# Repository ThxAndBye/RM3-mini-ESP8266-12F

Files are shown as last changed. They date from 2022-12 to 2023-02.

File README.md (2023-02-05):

# RM3-mini-ESP8266-12F
Replace the original uC PCB from the BroadLink RM3 mini with a ESP8266-12F

# BOM
|Part |Name |Amount  |
|---|---|---|
|R1-R2 |0603 5.1kΩ |2x |
|R3-R6 |0603 10kΩ |4x |
|R7 |0603 |1x |
|C1-C2 |0603 100nF |2x |
|C3-C4 |D5mm P2.5mm radial 47µF|2x |
|C5 |0603 10µF |1x |
|D4 |0603 LED |1x |
|J1 |TYPE-C-31-M-12 |1x |
|J3-J4 |2.54mm pin header |9x |
|U1 |ESP8266-12F |1x |
|U2 |AMS1117 3.3V |1x |
|RST & FLASH|6mm Push button |2x |

# PCB
## Front
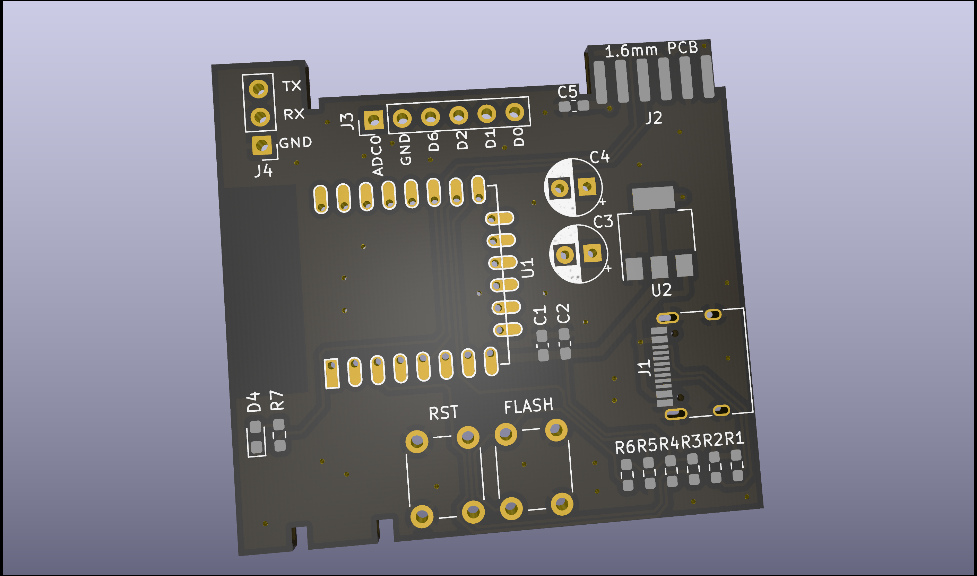
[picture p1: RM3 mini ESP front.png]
PCB front view


## Back
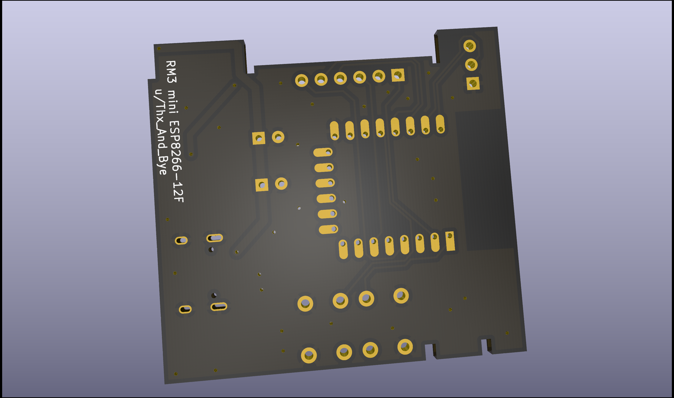
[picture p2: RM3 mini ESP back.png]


## Example ESPHome configuration
This example receives all IR codes and prins them to the log.
It also has the commands configured for the AUDIOPHONICS PRE-03.

```
esphome:
  name: "em3-mini"
  platform: esp8266
  board: esp01_1m

# Enable logging
logger:

# Enable Home Assistant API
api:

ota:

wifi:
  ssid: !secret wifi_ssid
  password: !secret wifi_password

  # Enable fallback hotspot (captive portal) in case wifi connection fails
  ap:
    ssid: "Esphome-Web-09F729"
    password: "QghgvaHWUIw2"

captive_portal:

light:
  - platform: status_led
    id: status
    name: "Status LED"
    pin: GPIO2
    
remote_receiver:
  pin:
    number: GPIO14
    inverted: true
  dump: all

remote_transmitter:
  pin: GPIO13
  carrier_duty_percent: 50%

button:
  - platform: template
    name: "Volume Up"
    on_press:
      - remote_transmitter.transmit_nec:
          address: 0xFF00
          command: 0xEF10
  - platform: template
    name: "Volume Down"
    on_press:
      - remote_transmitter.transmit_nec:
          address: 0xFF00
          command: 0xEB14
  - platform: template
    name: "Mute"
    on_press:
      - remote_transmitter.transmit_nec:
          address: 0xFF00
          command: 0xED12
  - platform: template
    name: "Switch input left"
    on_press:
      - remote_transmitter.transmit_nec:
          address: 0xFF00
          command: 0xEE11
  - platform: template
    name: "Switch input right"
    on_press:
      - remote_transmitter.transmit_nec:
          address: 0xFF00
          command: 0xEC13  
```

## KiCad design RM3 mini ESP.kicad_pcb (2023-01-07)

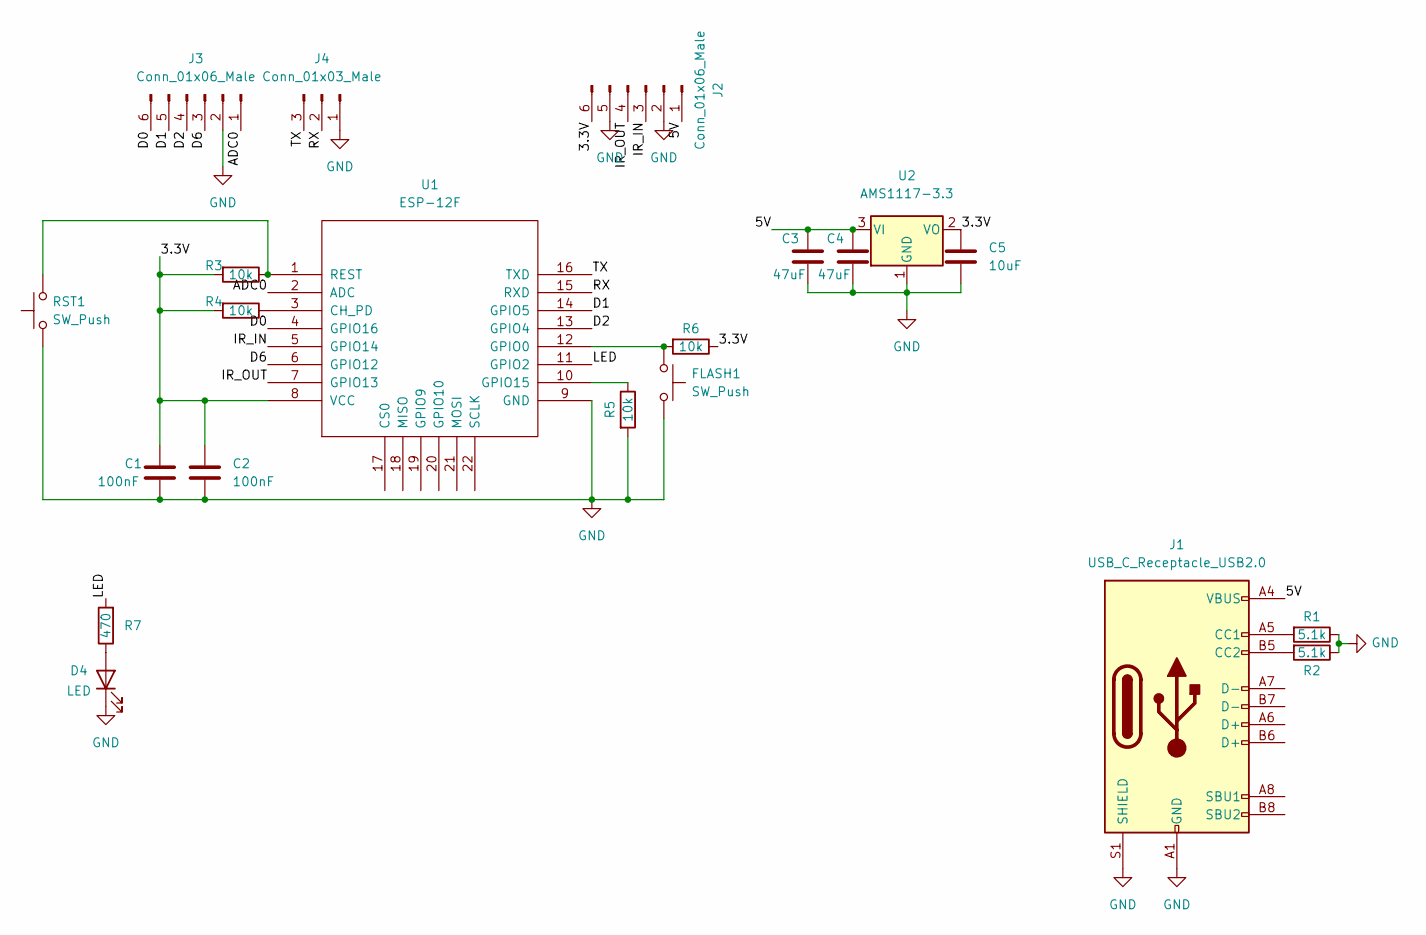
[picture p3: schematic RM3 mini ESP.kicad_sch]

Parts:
C1, C2: 100nF; C_0603_1608Metric_Pad1.08x0.95mm_HandSolder
C3, C4: 47uF; CP_Radial_D5.0mm_P2.50mm
C5: 10uF; C_0603_1608Metric_Pad1.08x0.95mm_HandSolder
D4: LED; LED_0603_1608Metric_Pad1.05x0.95mm_HandSolder
FLASH1: SW_Push; SW_PUSH_6mm_H8mm
J1: USB_C_Receptacle_USB2.0; USB_C_Receptacle_HRO_TYPE-C-31-M-12
J2: Conn_01x06_Male; SolderWirePad_1x01_SMD_1x2mm
J3: Conn_01x06_Male; PinHeader_1x06_P2.54mm_Vertical
J4: Conn_01x03_Male; PinHeader_1x03_P2.54mm_Vertical
R1, R2: 5.1k; R_0603_1608Metric_Pad0.98x0.95mm_HandSolder
R3, R4, R5, R6: 10k; R_0603_1608Metric_Pad0.98x0.95mm_HandSolder
R7: 470; R_0603_1608Metric_Pad0.98x0.95mm_HandSolder
RST1: SW_Push; SW_PUSH_6mm_H8mm
U1: ESP-12F; ESP-12E
U2: AMS1117-3.3; SOT-223-3_TabPin2

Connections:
/3.3V: C1.1, C2.1, C5.1, J2.6, R3.2, R4.2, R6.1, U1.8 (VCC), U2.2 (VO)
/5V: C3.1, C4.1, J1.A4 (VBUS), J1.A9 (VBUS), J1.B4 (VBUS), J1.B9 (VBUS), J2.1, U2.3 (VI)
/ADC0: J3.1, U1.2 (ADC)
/D0: J3.6, U1.4 (GPIO16)
/D1: J3.5, U1.14 (GPIO5)
/D2: J3.4, U1.13 (GPIO4)
/D6: J3.3, U1.6 (GPIO12)
/IR_IN: J2.3, U1.5 (GPIO14)
/IR_OUT: J2.4, U1.7 (GPIO13)
/LED: R7.2, U1.11 (GPIO2)
/RX: J4.2, U1.15 (RXD)
/TX: J4.3, U1.16 (TXD)
GND: C1.2, C2.2, C3.2, C4.2, C5.2, D4.1 (K), FLASH1.2, J1.A1 (GND), J1.A12 (GND), J1.B1 (GND), J1.B12 (GND), J1.S1 (SHIELD), J2.2, J2.5, J3.2, J4.1, R1.1, R2.1, R5.2, RST1.1, U1.9 (GND), U2.1 (GND); also elsewhere on the board
unnamed: D4.2 (A), R7.1
unnamed: J1.A5 (CC1), R1.2
unnamed: J1.B5 (CC2), R2.2
unnamed 16: R3.1, RST1.2, U1.1 (REST); also elsewhere on the board
unnamed: R4.1, U1.3 (CH_PD)
unnamed: R5.1, U1.10 (GPIO15)
unnamed 19: FLASH1.1, R6.2, U1.12 (GPIO0); also elsewhere on the board

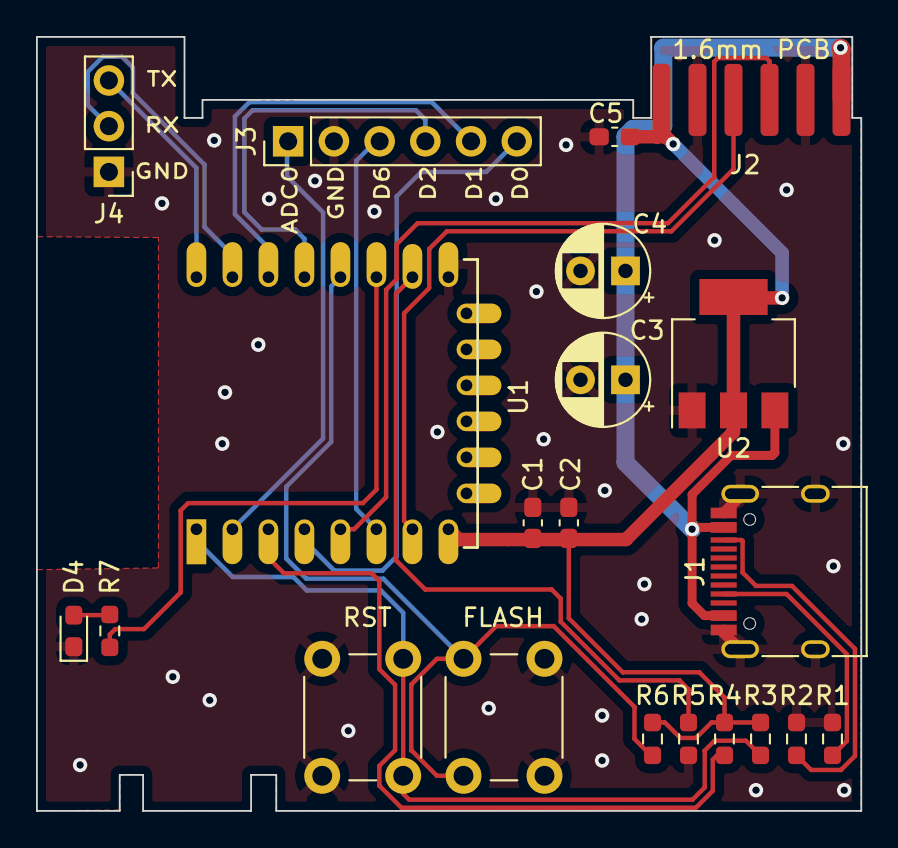
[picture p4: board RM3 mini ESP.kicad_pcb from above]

Board: 2 copper layers, 45.8 x 43.0 mm, 21 parts (0 on the bottom side), 20 nets.

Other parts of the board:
FLASH: SW_Push; SW_PUSH_6mm_H8mm
RST: SW_Push; SW_PUSH_6mm_H8mm

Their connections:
GND: FLASH.2, RST.1; also elsewhere on the board
unnamed 16: RST.2; also elsewhere on the board
unnamed 19: FLASH.1; also elsewhere on the board

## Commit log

2022-12-26 PCB and Gerber initial commit
    [RM3 mini ESP-B_Cu.gbr, RM3 mini ESP-B_Mask.gbr, RM3 mini ESP-B_Silkscreen.gbr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]
2022-12-26 Add BOM & images to README.md
2022-12-26 Small correction for edge connector
    [RM3 mini ESP.kicad_pcb]
2022-12-26 Update Gerber
    [RM3 mini ESP-B_Cu.gbr, RM3 mini ESP-B_Mask.gbr, RM3 mini ESP-B_Silkscreen.gbr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]
2023-01-07 minimal size adjust to fit the case
    [RM3 mini ESP.kicad_pcb]
